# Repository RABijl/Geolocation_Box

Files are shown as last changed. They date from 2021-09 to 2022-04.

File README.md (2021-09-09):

# Geolocation_Box

The result of a personal hobby, the geolocation box is a little arduino powered chest that only opens when one brings the box the right geological location. A little screen on top of it indicates how far one is from the location.

## Parts list
The parts have been bought from local Dutch websites, but should also easily be available in international markets.

* [Arduino nano V3](https://www.tinytronics.nl/shop/en/development-boards/microcontroller-boards/arduino-compatible/nano-v3.0-with-usb-cable)
* [ 5V buck converter ](https://www.tinytronics.nl/shop/en/power/voltage-converters/buck-(step-down)-converters/dc-dc-step-down-buck-converter-1.5a-5v-output)
* [SG90 servo](https://www.tinytronics.nl/shop/en/mechanics-and-actuators/motors/servomotors/sg90-mini-servo)
* [Sparkfun bi-directional logicl level converter](https://www.kiwi-electronics.nl/en/sparkfun-logic-level-converter-bi-directional-3154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)
* [ATGM336H GPS module](https://www.tinytronics.nl/shop/en/communication-and-signals/wireless/gps/modules/atgm336h-gps-module)
* [64*32 pixel OLED display](https://www.tinytronics.nl/shop/en/displays/oled/0.49-inch-oled-display-64*32-pixels-white-i2c)
* [Generic switch](https://www.tinytronics.nl/shop/en/switches/manual-switches/slide-switches/small-switch-for-pcb-or-breadboard)
* [9V battery clip](https://www.tinytronics.nl/shop/en/power/battery-holders-and-clips/9v/9v-battery-clip-with-loose-wires-15cm-soft)
* [Wooden box](https://lumarhobby.nl/detail/2312810/houten-kist-boekvorm-20cm-x-14-1cm-x-6-9cm-paulownia.htm)
* Assortment of wires
* PCB protoboard

## Tools

* Soldering iron
* Hotglue gun
* Dremel rotary tool
* wire strippers
* 3D printer (Ender 3 in my case)
* sanding tools
* Screwdriver   

## Software

* VSCode with platformIO
* PrusaSlicer
* TinkerCad
* Fritzing (in the future)

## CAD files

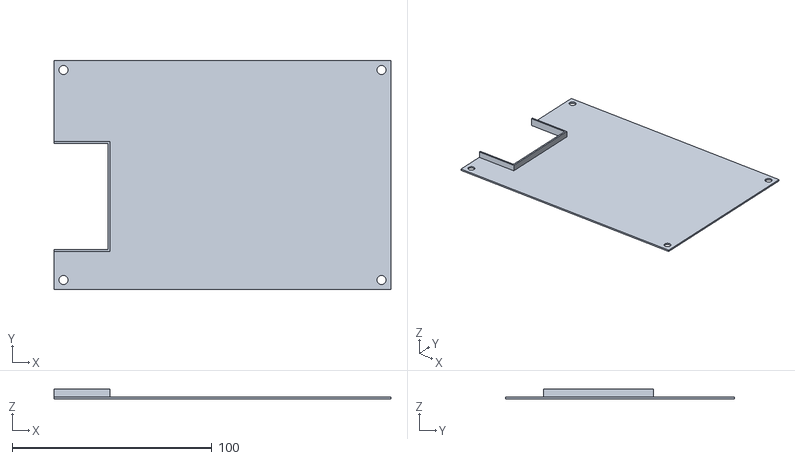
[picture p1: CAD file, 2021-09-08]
models/bottom_main.stl
168.5 x 114.5 x 5.00

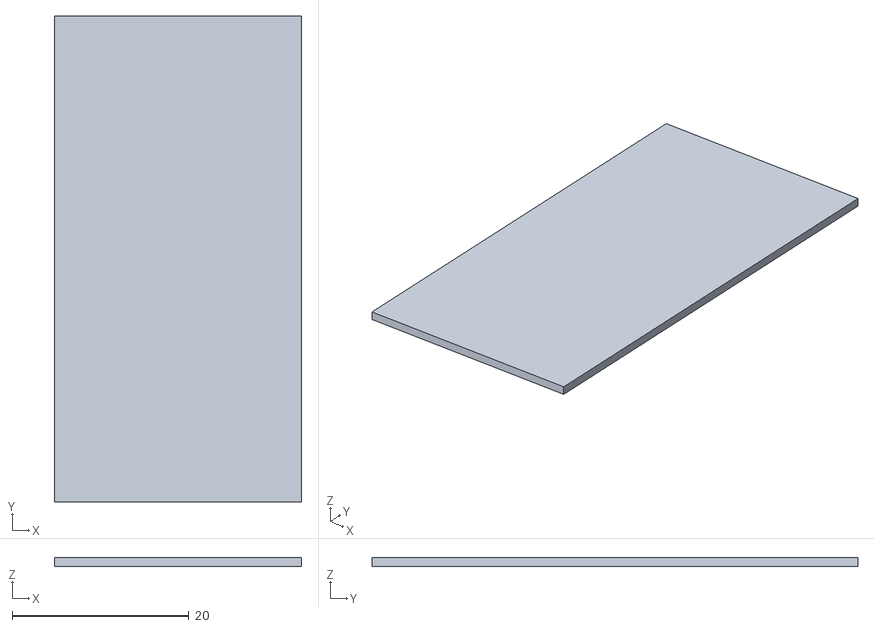
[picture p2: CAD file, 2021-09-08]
models/battery_top.stl
28.0 x 55.0 x 1.00

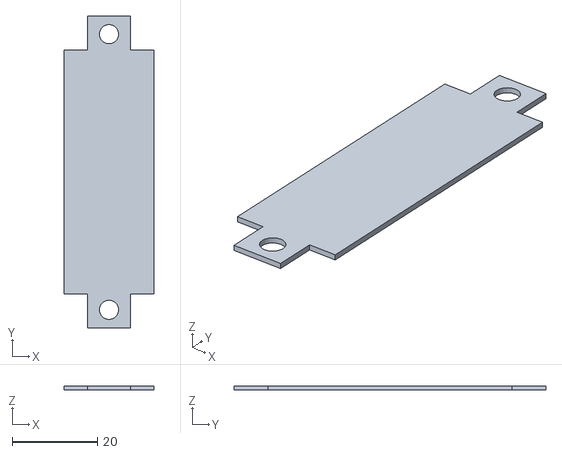
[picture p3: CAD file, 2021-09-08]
models/battery case.stl
21.0 x 73.0 x 1.00

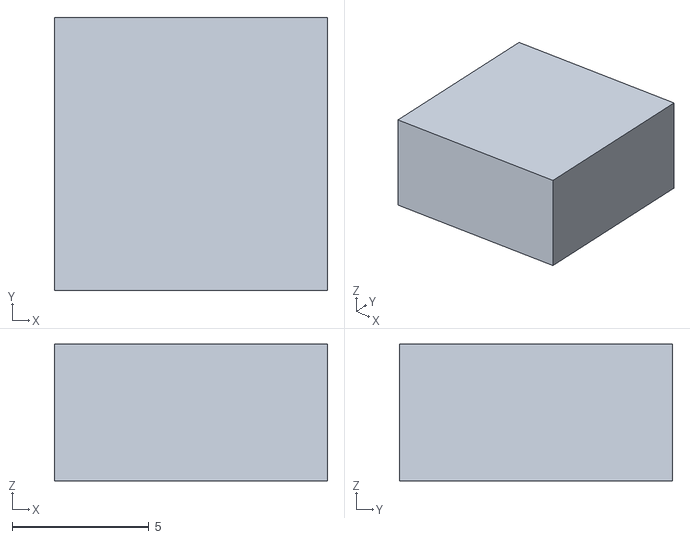
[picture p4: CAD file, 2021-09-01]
models/board_standoff.stl
10.0 x 10.0 x 5.00

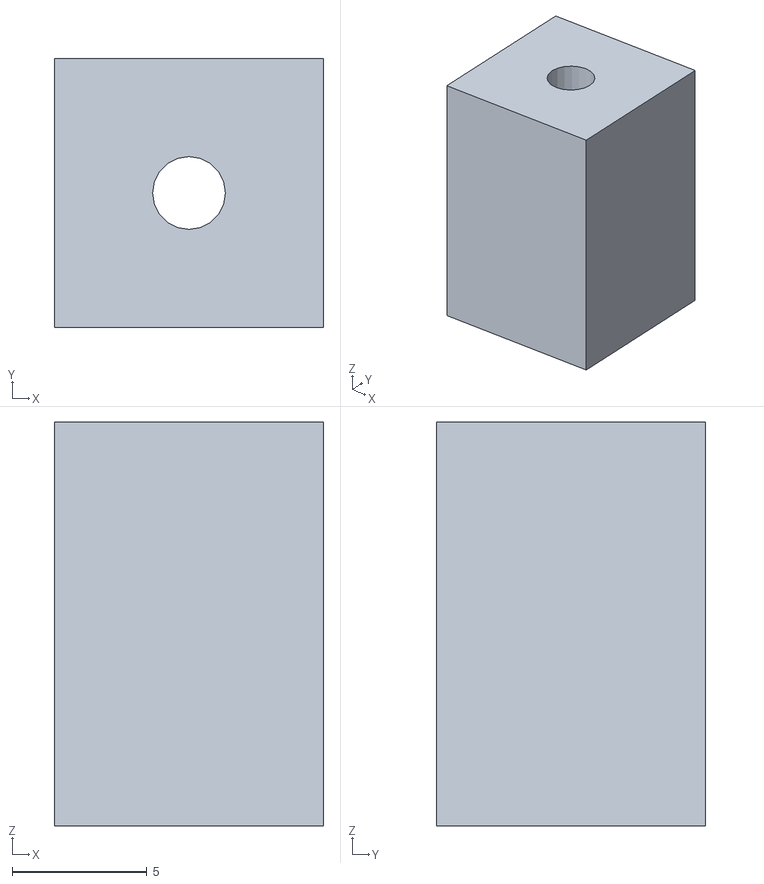
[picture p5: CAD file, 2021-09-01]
models/lid_standoff.stl
10.0 x 10.0 x 15.0

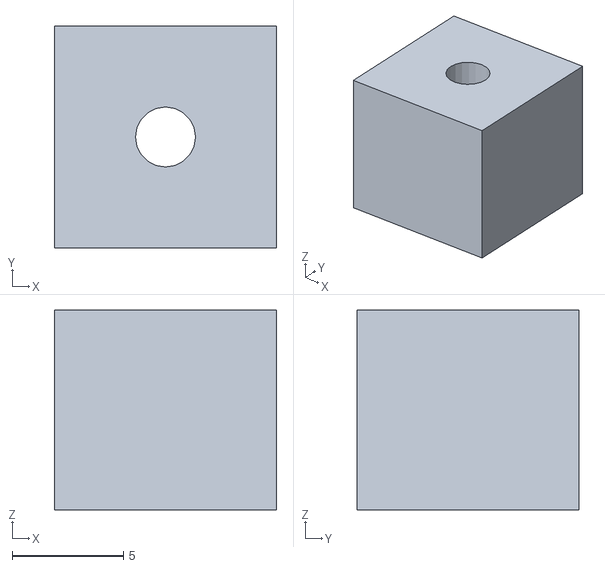
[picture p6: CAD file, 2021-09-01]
models/lower_lid_standoff.stl
10.0 x 10.0 x 9.00

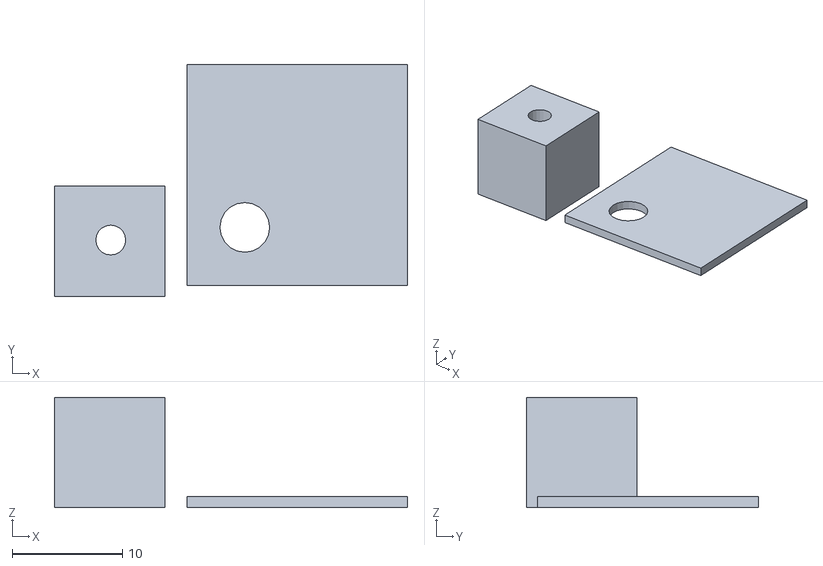
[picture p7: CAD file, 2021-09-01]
models/test_holes_2.7_4.5.stl
32.0 x 21.0 x 10.0

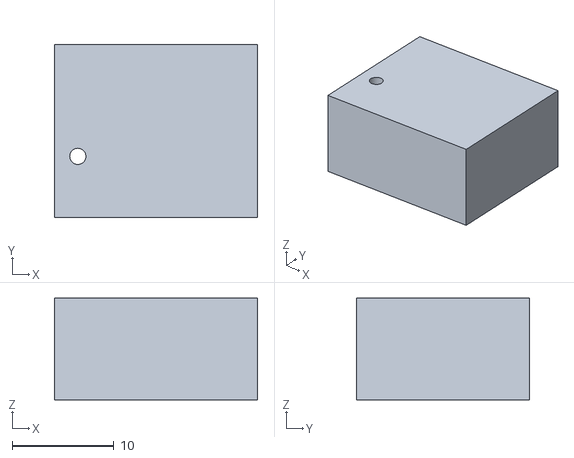
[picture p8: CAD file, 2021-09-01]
models/servo block.stl
20.0 x 17.0 x 10.0

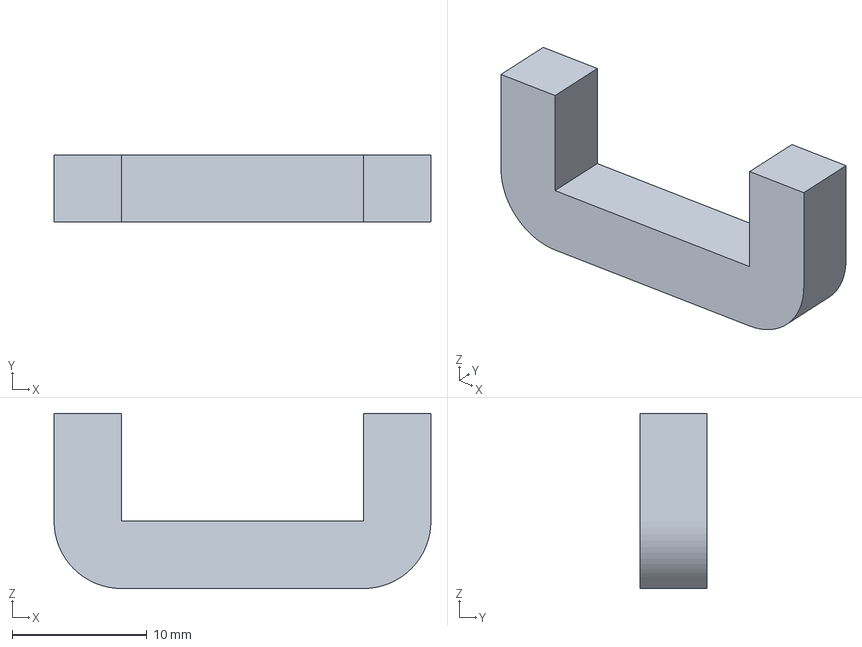
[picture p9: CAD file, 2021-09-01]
models/lock_brace.3mf
28.0 x 5.00 x 13.0 mm

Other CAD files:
models/servo block R.stl
models/lock_brace.stl

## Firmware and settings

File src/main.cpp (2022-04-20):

#include <TinyGPS++.h>
#include <SoftwareSerial.h>
#include <U8g2lib.h>
#include <Wire.h>
#include <Servo.h>

// comment out to disable useful info over serial monitor
#define DEBUG

//// config section ////
static const double DESTLAT = 52.07856682313063, DESTLON = 4.3037621602385;

static const unsigned long SERIALBAUD = 9600;
static const int TOTALCHARS = 6;
static const unsigned int DESTPRECISION = 30;

//// function headers ////
static void smartDelay(unsigned long ms);
static void ToDisplay(char *str, int sats);
static void IntToCharArray(char *out, int len, unsigned long val, bool valid);
static void LoadingAnimation(char *res, int len);
static void GetSignalString(char *out, int sats);

//// GPS ////
static const unsigned long GPSBaud = 9600;
SoftwareSerial ss(PIN3, PIN4); // ss(RX,TX)
TinyGPSPlus gps;

//// LCD ////
U8G2_SSD1306_64X32_1F_F_HW_I2C u8g2(U8G2_R0, U8X8_PIN_NONE);

//// servo ////
Servo servo;
static const int LOCKPOS = 30, OPENPOS = 150;
int pos = LOCKPOS, newPos = LOCKPOS;

void setup()
{
  Serial.begin(SERIALBAUD);
  ss.begin(GPSBaud);

  u8g2.begin();

  servo.attach(PIN7);
  servo.write(LOCKPOS);
  delay(100);
  servo.write(LOCKPOS);
  delay(100);
  servo.detach();

#ifdef DEBUG
  Serial.println("started up box");
#endif
}

void loop()
{
  // cast to unsigned int since distance is positive and we are not interested in decimals
  unsigned long distance = (unsigned long)TinyGPSPlus::distanceBetween(gps.location.lat(),
                                                                       gps.location.lng(),
                                                                       DESTLAT,
                                                                       DESTLON);

  char str[TOTALCHARS + 1];
  IntToCharArray(str, TOTALCHARS, distance, gps.location.isValid());
  ToDisplay(str, gps.satellites.value());

  // open or close box
  newPos = distance < DESTPRECISION ? OPENPOS : LOCKPOS;
  if (pos != newPos)
  {

#ifdef DEBUG
    Serial.print("new servo pos: ");
    Serial.println(newPos);
#endif

    servo.attach(PIN7);
    delay(100);
    servo.write(newPos);
    delay(100);
    // send message again incase previous one wasn't received
    servo.write(newPos);
    delay(100);
    servo.detach();

    pos = newPos;
  }

#ifdef DEBUG
  // debugging purposes
  Serial.print("distance to point: ");
  Serial.println(distance);
  Serial.print("number of satellites: ");
  Serial.println(gps.satellites.value());
  Serial.print("current lat and lon: ");
  Serial.print(gps.location.lat(), 5);
  Serial.print(",");
  Serial.println(gps.location.lng(), 5);
  Serial.println("--------------------------");
#endif

  smartDelay(1000);
}

// make sure that gps serial is not blocked
static void smartDelay(unsigned long ms)
{
  unsigned long start = millis();
  do
  {
    while (ss.available())
    {
      gps.encode(ss.read());
    }

  } while (millis() - start < ms);
}

// print to the display
// assuming a 64*32 display and displaying 6 chars
static void ToDisplay(char *str, int sats)
{
  u8g2.clearBuffer();

  u8g2.setFont(u8g2_font_10x20_tn);
  u8g2.drawStr(2, 26, str);

  if (sats > 0)
  {
    char signal[sats + 1];
    GetSignalString(signal, sats);
    u8g2.setFont(u8g2_font_4x6_tn);
    u8g2.drawStr(0, 6, signal);
  }

  u8g2.sendBuffer();
}

static void GetSignalString(char *out, int sats)
{
  for (int i = 0; i < sats; i++)
  {
    out[i] = '-';
  }
  // indicate end of string
  out[sats] = 0;
}

// create char array to be displayed
static void IntToCharArray(char *out, int len, unsigned long val, bool valid)
{

  if (valid)
  {
    sprintf(out, "%.6ld", val);
  }
  else
  {
    LoadingAnimation(out, len);
  }

  out[len] = 0;
}

// create a chare array with a moving circle to indicate system is doing something
int counter = 0;
static void LoadingAnimation(char *res, int len)
{
  if (counter > len - 1)
  {
    counter = 0;
  }
  else
  {
    counter++;
  }

  for (int i = 0; i < len; ++i)
  {
    if (i == counter)
    {
      res[i] = '0';
    }
    else
    {
      res[i] = '-';
    }
  }
}

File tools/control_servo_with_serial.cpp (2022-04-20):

#include "Arduino.h"
#include <Servo.h>

#ifdef U8X8_HAVE_HW_SPI
#include <SPI.h>
#endif
#ifdef U8X8_HAVE_HW_I2C
#include <Wire.h>
#endif

Servo serv;
int pos = 0;
int newPos = 0;

bool handleInp = false;

void setup()
{
  // initialize LED digital pin as an output.
  pinMode(LED_BUILTIN, OUTPUT);
  serv.attach(PIN5);
  Serial.begin(9600);
}

void loop()
{
    if (handleInp == true) {
        digitalWrite(LED_BUILTIN, HIGH);
        if(newPos != pos){
          serv.write(newPos);
          pos = newPos;
          delay(300);
        }
        handleInp = false;
        delay(300);
        digitalWrite(LED_BUILTIN, LOW);

    }


}

String line = "";
void serialEvent()
{
  
   while(Serial.available()) 
   {
     
     char ch = Serial.read();
     if(ch == '\n' ){
        Serial.println("received this: " +line);
        newPos = line.toInt();
        handleInp = true;
        line="";
        
     }else if(ch != 13){
       line += ch;
     }

   }
}

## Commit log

2021-07-22 tried out servo library
2021-07-22 adds servo lib
2021-07-23 reverts main to blinking led again
    [main.cpp]
2021-08-18 control servo with serial messages
2021-08-22 adds servo code
2021-08-31 switches software serial pins
2021-09-01 adds servo and test hole files
    [lock_brace.3mf, lock_brace.stl, servo block R.stl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]
2021-09-01 moved servo wire to different pin
2021-09-01 adds standoff files
    [board_standoff.stl, lid_standoff.stl, lower_lid_standoff.stl]
2021-09-08 adds final pieces
    [battery case.stl, battery_top.stl, bottom_main.stl]
